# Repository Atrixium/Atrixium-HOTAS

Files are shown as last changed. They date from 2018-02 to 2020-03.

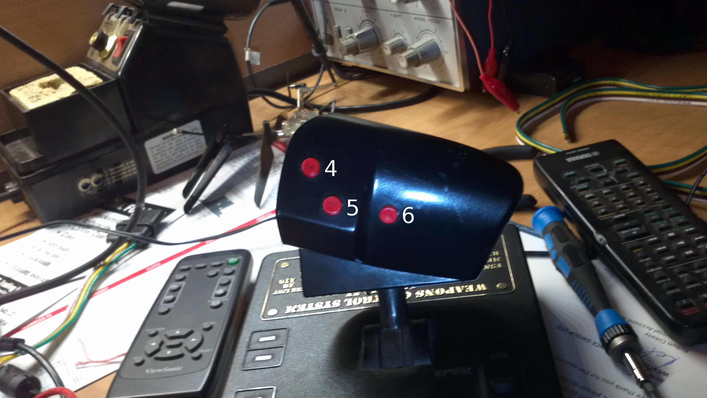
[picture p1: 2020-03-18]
Finger Tip Buttons.png

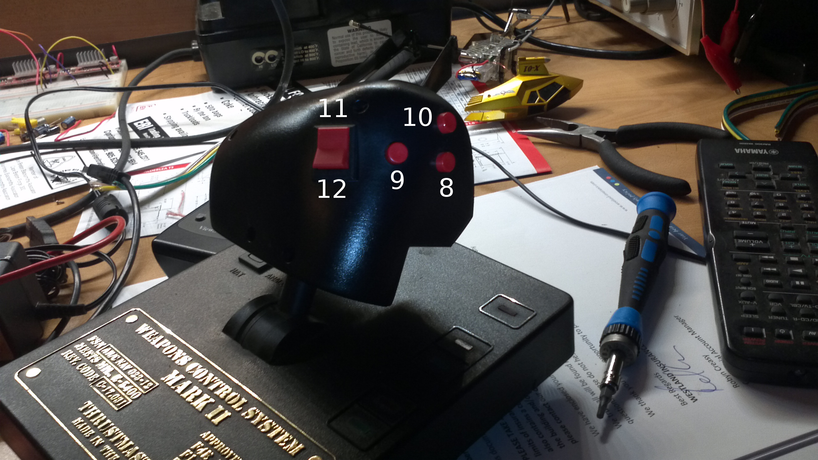
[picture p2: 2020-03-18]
Thumb Buttons.png

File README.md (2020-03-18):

# Atrixium-HOTAS

This is a simple HOTAS flight stick for Sparkfun Pro Micro boards (and clones) it uses the excellent NicoHood Gamepad API as the core https://github.com/NicoHood/HID as well as leveraging the SPI library for efficiently reading the shift registers. The code is pretty rough but is functional and it's fast enough for real gameplay, I have plans to integrate a better ADC in the future in the form of the Adafruit ADS1115 16bit, 4 channel ADC.

Schematics and board files are in CADsoft Eagle format.

Additional info on this HOTAS can be found on my Youtube channel: https://www.youtube.com/user/Atrixium

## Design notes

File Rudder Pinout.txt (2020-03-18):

Mini DIN connecter MD-60s

1 - Ground - Grn
5 - Analog Data - White
4 - VCC - Yel
6 - Digital Data

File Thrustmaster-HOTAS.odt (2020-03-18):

Thrustmaster Top Gun, WCS MK II HOTAS
& Rudder System

Objective:

Convert Thrustmaster WCS MK II into base unit for Top Gun Flightstick and custom rudder pedals for use with modern games on a Linux system. Peripherals attach to WCS MK II and it connects to PC via USB.

Specifications:

Top Gun
2 Axes, 4 Buttons, 4 Pos POV hat (Analog)

15 pin DSUB output

WCS MK II
1 Axis, 6 buttons, 2 on-off-on rocker switches, 1 on-off rocker switch
15 pin DSUB input (for Top Gun)

6 Pin mini din (MD-60S) input for rudder

USB A Output

Rudder Pedals
1 axis, 1 button

6 Pin mini din (MD-60S)

Components:

x1 Pro Micro Microcontroller running NicoHood\HID Library https://github.com/NicoHood/HID/wiki
x2 MC74HC165A 8 bit PISO shift registers for button scanning

x2 MD-60S Connectors for rudder connection

Process:

Joystick pots need to be rewired to allow for direct reading of the pots, they currently have signal and VCC connections. VCC must be moved to an outer position, signal must be moved to the wiper and a ground must be added. Throttle will be entirely rewired, switches and buttons are all common grounded.

Pinouts


Analog | Digital
A0) Flightstick X | MISO) SR Data out (SR Pin 9 or 7 for inverse)
A1) POV Hat | SCLK) SR Clock (SR Pin 2)
A2) Flightstick Y | 10) SR Shift/Load (SR Pin 1)
A9) Throttle
A3) Rudder

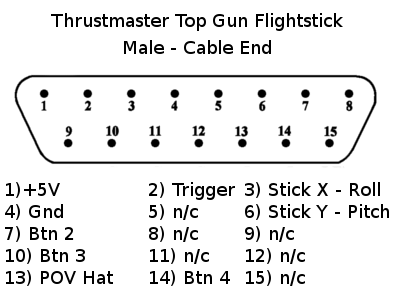
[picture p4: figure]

gnd - yellow | btn1 – red | btn2 – purple | btn3 – blue | btn4 – green | vcc - orange & brown

Function Description

A button is pressed which pulls its corresponding data line low, setting the shift register input to low, the microcontroller shifts in 2 bytes of data from the shift registers inverted output via SPI and processes it by bit-masking to determine which buttons are pressed, this should be executed as many times per second as possible.

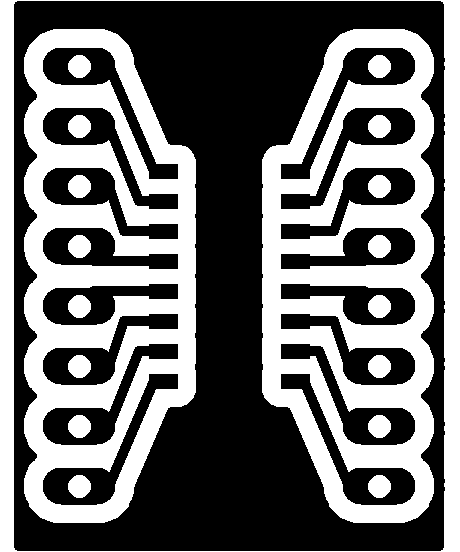
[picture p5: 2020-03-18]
SO16 Breakout v2.png

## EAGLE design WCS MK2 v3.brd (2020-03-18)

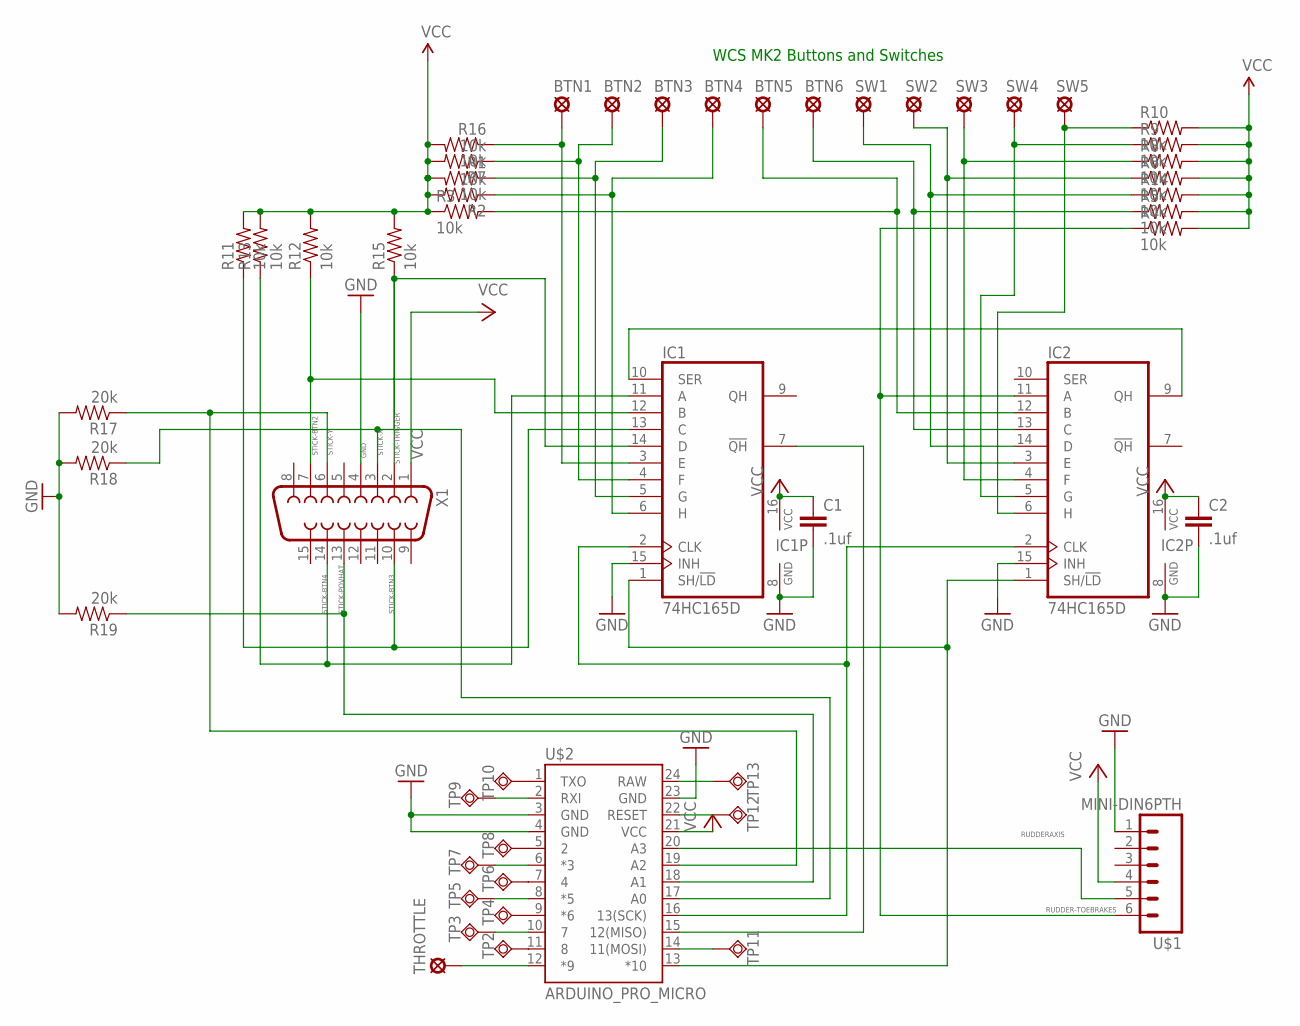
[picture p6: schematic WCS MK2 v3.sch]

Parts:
BTN1, BTN2, BTN3, BTN4, BTN5, BTN6: LSP10
C1, C2: .1uf; C025-060X050
IC1, IC2: 74HC165D; SO16
R1, R2, R3, R4, R5, R6, R7, R8, R9, R10, R11, R12, R13, R14, R15, R16: 10k; AXIAL-0.1
R17, R18, R19: 20k; AXIAL-0.1
SW1, SW2, SW3, SW4, SW5: LSP10
THROTTLE: LSP10
TP2, TP3, TP4, TP5, TP6, TP7, TP8, TP9, TP10, TP11, TP12, TP13: TPSQTP20SQ; TP20SQ
U$1: MINI-DIN6PTH; MINI-DIN6
U$2: ARDUINO_PRO_MICRO
X1: F15HP

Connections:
CLOCK: IC1.2 (CLK), IC2.2 (CLK), U$2.16 (13(SCK))
DAISYCHAIN: IC1.10 (SER), IC2.9 (QH)
GND: C1.2, C2.2, IC1.8 (GND), IC1.15 (INH), IC2.8 (GND), IC2.15 (INH), R17.P$2 (2), R18.P$2 (2), R19.P$2 (2), U$1.1, U$2.3 (GND), U$2.4 (GND), U$2.23 (GND), X1.4
MISO: IC1.7 (!QH), U$2.15 (12(MISO))
unnamed: BTN1.MP, IC1.3 (E), R16.P$1 (1)
unnamed: BTN2.MP, IC1.4 (F), R7.P$1 (1)
unnamed: BTN3.MP, IC1.5 (G), R1.P$1 (1)
unnamed: BTN4.MP, IC1.6 (H), R2.P$1 (1)
unnamed: IC2.6 (H), R10.P$1 (1), SW5.MP
unnamed: IC2.5 (G), R9.P$1 (1), SW4.MP
unnamed: IC2.4 (F), R8.P$1 (1), SW3.MP
unnamed: IC2.3 (E), R6.P$1 (1), SW2.MP
unnamed: IC2.14 (D), R14.P$1 (1), SW1.MP
unnamed: BTN6.MP, IC2.13 (C), R5.P$1 (1)
unnamed: BTN5.MP, IC2.12 (B), R3.P$2 (2)
unnamed: TP2.TP, U$2.11 (8)
unnamed: TP3.TP, U$2.10 (7)
unnamed: TP4.TP, U$2.9 (*6)
unnamed: TP5.TP, U$2.8 (*5)
unnamed: TP6.TP, U$2.7 (4)
unnamed: TP7.TP, U$2.6 (*3)
unnamed: TP8.TP, U$2.5 (2)
unnamed: TP9.TP, U$2.2 (RXI)
unnamed: TP10.TP, U$2.1 (TXO)
unnamed: TP11.TP, U$2.14 (11(MOSI))
unnamed: TP12.TP, U$2.22 (RESET)
unnamed: TP13.TP, U$2.24 (RAW)
RUDDER-TOEBRAKES: IC2.11 (A), R4.P$1 (1), U$1.6
RUDDERAXIS: U$1.5, U$2.20 (A3)
SR-LOAD: IC1.1 (SH/!LD), IC2.1 (SH/!LD), U$2.13 (*10)
STICK-BTN2: IC1.12 (B), R12.P$1 (1), X1.7
STICK-BTN3: IC1.13 (C), R11.P$1 (1), X1.10
STICK-BTN4: IC1.11 (A), R13.P$1 (1), X1.14
STICK-POVHAT: R19.P$1 (1), U$2.18 (A1), X1.13
STICK-TRIGGER: IC1.14 (D), R15.P$1 (1), X1.2
STICK-X: R18.P$1 (1), U$2.17 (A0), X1.3
STICK-Y: R17.P$1 (1), U$2.19 (A2), X1.6
THROTTLEAXIS: THROTTLE.MP, U$2.12 (*9)
VCC: C1.1, C2.1, IC1.16 (VCC), IC2.16 (VCC), R1.P$2 (2), R2.P$2 (2), R3.P$1 (1), R4.P$2 (2), R5.P$2 (2), R6.P$2 (2), R7.P$2 (2), R8.P$2 (2), R9.P$2 (2), R10.P$2 (2), R11.P$2 (2), R12.P$2 (2), R13.P$2 (2), R14.P$2 (2), R15.P$2 (2), R16.P$2 (2), U$1.4, U$2.21 (VCC), X1.1

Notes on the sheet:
WCS MK2 Buttons and Switches

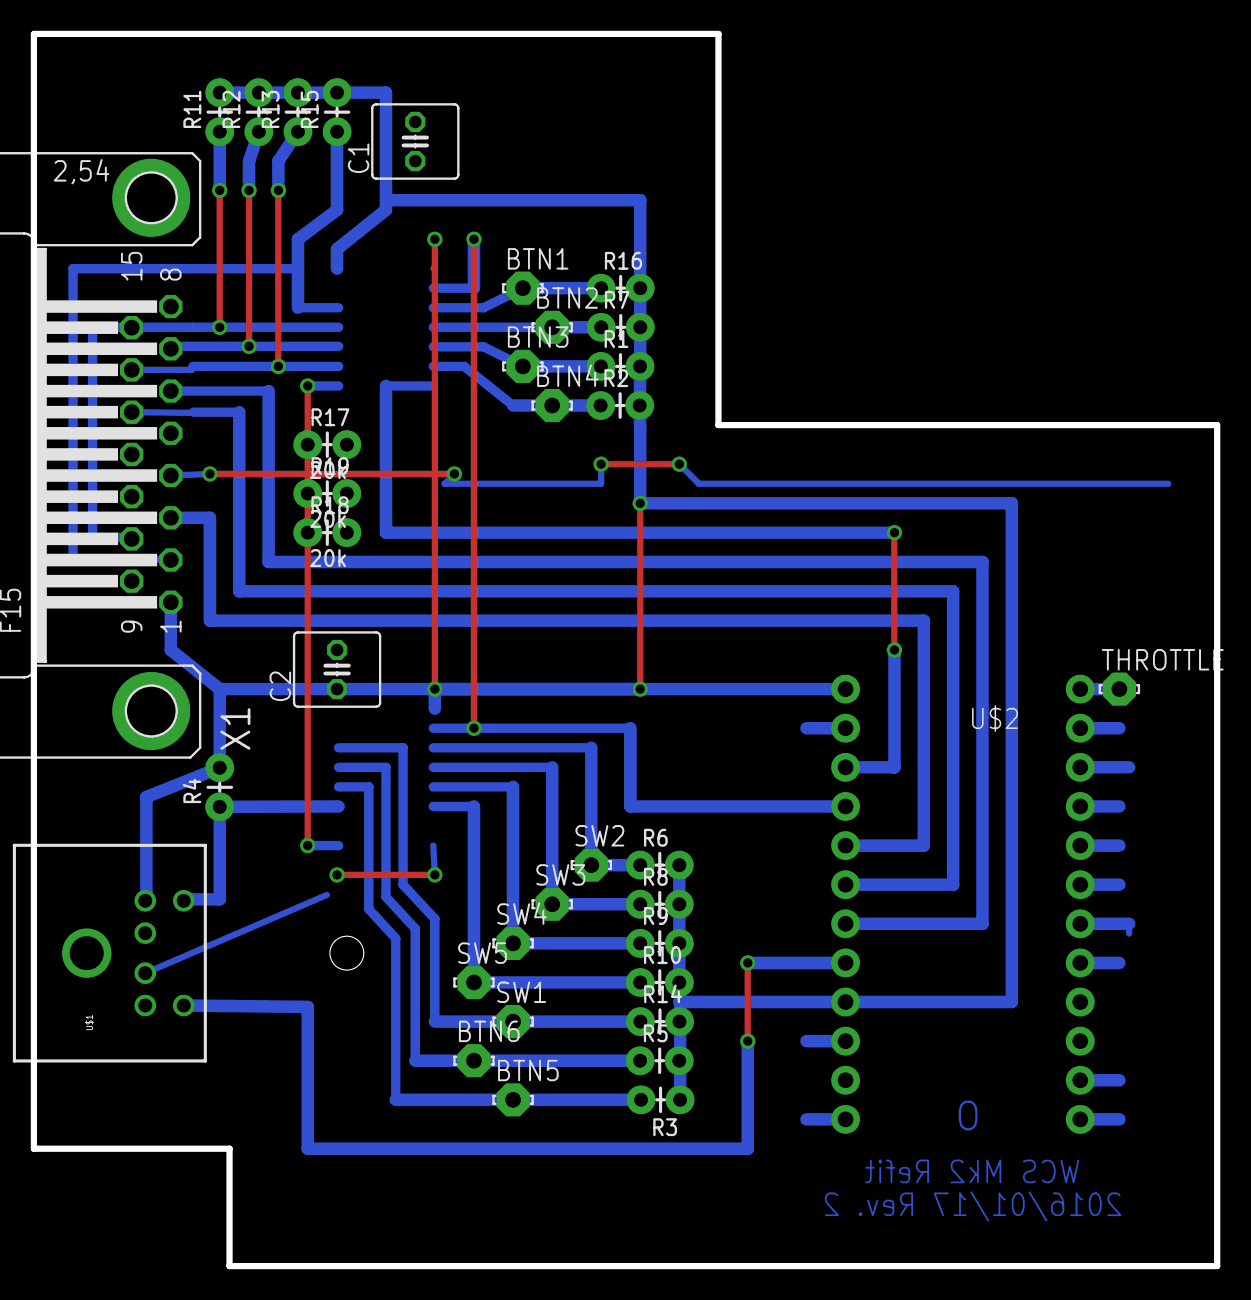
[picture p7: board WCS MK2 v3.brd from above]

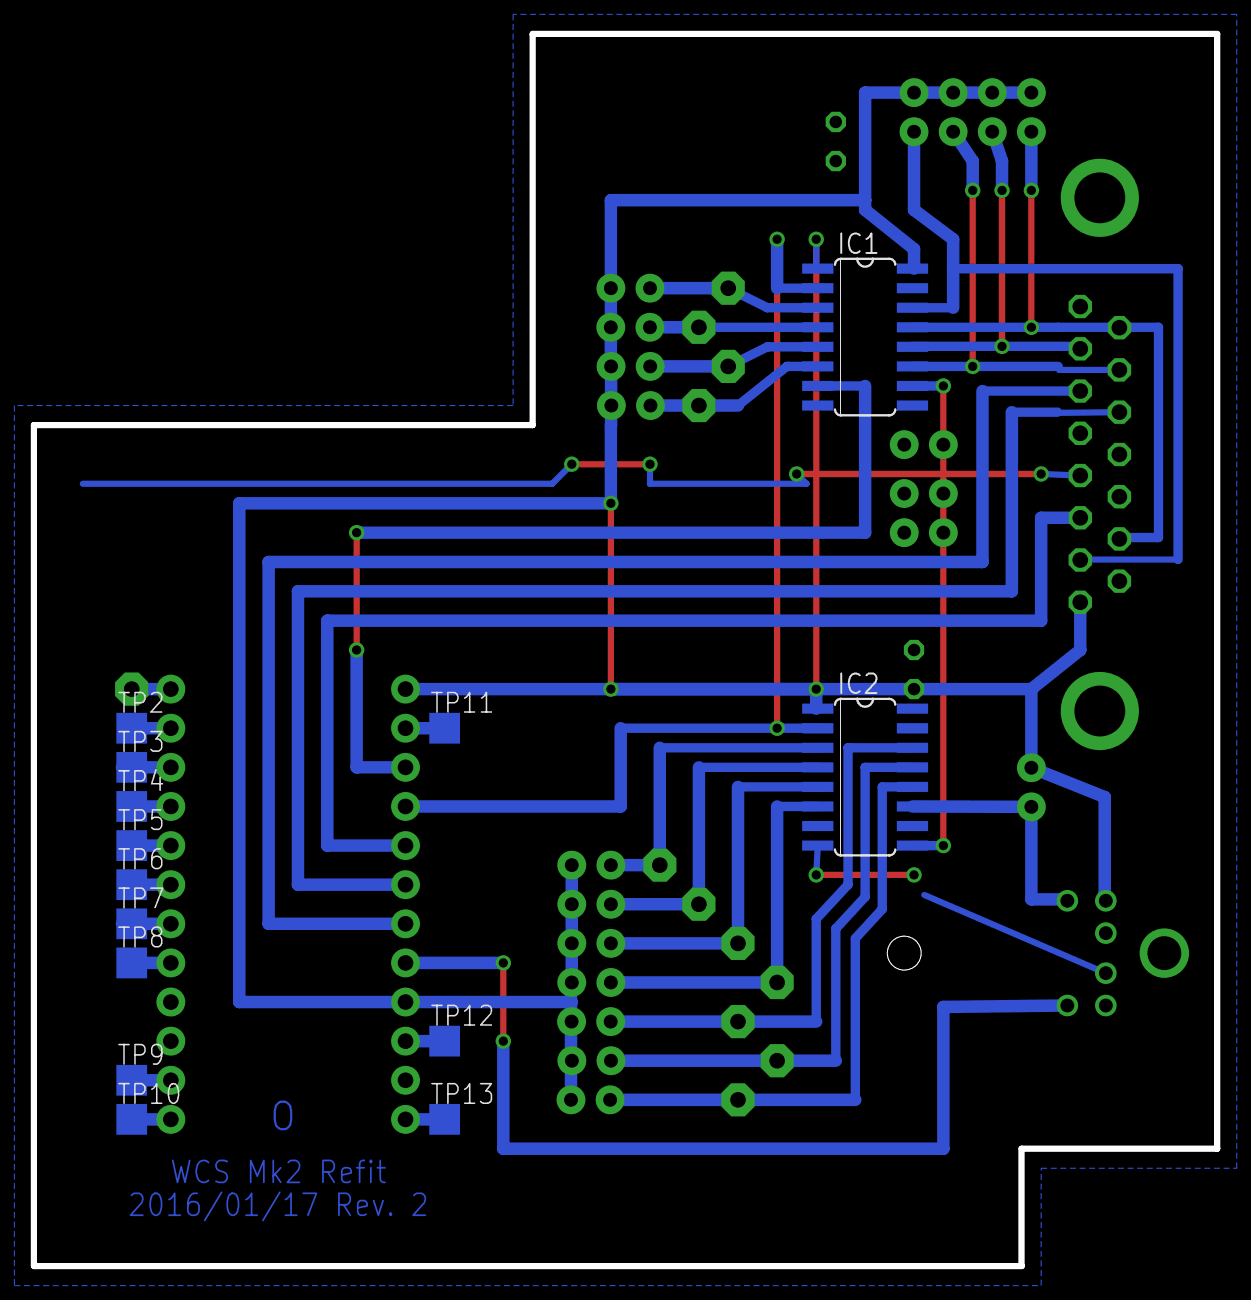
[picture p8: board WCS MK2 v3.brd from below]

Board: 2 copper layers, 76.8 x 80.0 mm, 50 parts (14 on the bottom side), 39 nets.

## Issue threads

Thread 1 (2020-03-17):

circuit schematic/pcb layout

minipc, 2020-03-17:
more of a request than issue:

i was wondering if either the circuit schematic or pcb layout for this project were available anywhere? and if not if they could be made available?

i have scrutinised frame grabs of the pcb layout and assembled pcb taken from the second and first youtubes relating to this project and am having trouble reconciling the positions of the resistors and bridging connectors visible in the finished assembly featured in the first video with positions of the solder pads of the pcb layout featured in the second video.

Atrixium, 2020-03-18:
Sorry about that, the documentation is... Not great. I never actually expected anyone else to see this project! I'm sure I have everything backed up, board layout, PCB etc, so I'll make sure to get it all on here and answer any questions you might have!

Atrixium, 2020-03-18:
I just uploaded basically all I have on the project, hopefully that helps. I remember something about having to bodge something on the board as well, so I'll take it apart later on and see if I can remember what it was.

minipc, 2020-03-18:
no need to apologise :) i guess interest in the project may largely depend on how many people happen to have vintage thrustmaster sticks and throttles they're considering upgrading to the 21st century ;)

i happen to have a basically unused thrustmaster pro flight control system stick and am wondering if it's worth trying to source a weapons control system ii throttle in order to do a conversion similar to yours, or whether to just convert the stick alone. the possibility of restricting mods to a potentially beat up second hand throttle, and leaving the stick in pristine condition seemed attractive, although i note from what you've uploaded that some modification of the stick's wiring is unavoidable.

there are a number of youtube tutorials that cover the use of shift registers and pots with arduinos. and there are clues in the arduino sketch. so i could have probably inferred that side of things, if i'd really put my mind to it. what wasn't so clear was how the game and ps2 ports connected up. which is why i reached out.

it's interesting that you mention perhaps bodging something on the pcb. while comparing the youtubes, i did wonder if i was looking at two different versions of it. indeed, the layout in the uploaded brd file is quite different from that shown in the second youtube.

thank you so much for such a speedy and thorough response. the brd file alone will be a great help. all i can think of further to ask is whether with hindsight there was anything you might have done differently, like perhaps locating the pro micro board closer to the edge of the pcb? or was there some reason to set the micro usb connector back from the side of the enclosure? actually, i think you've already done enough for the issue to be closed :)

Atrixium, 2020-03-18:
The design decisions were mostly fueled by my inexperience :) Going back and doing it again I definitely would have either mounted the micro in such a way that the USB port was easier to get to, or wired in an extension to allow better port placement. I think I also would have gone straight to the 16bit ADC, the 10 bits of precision Saree good enough and on par with most joysticks, but why not make it better :)

I think a better electrical engineer (I'm just a self-taught hobbyist) could have made the circuit work without modifying the joystick, but I couldn't figure out how to do it at the time and I also figured I'd never have another machine with a game port connection :)

Anyway, thanks for your interest in the project and I'll post any other useful tidbits as I recall them! I'd really like to finish this project and get the rudders working properly but real life keeps getting in the way!

minipc, 2020-03-19:
thanks for sharing your insights.

i'm guessing that the gameport standard involved the analogue signals being read as some kind of measurement of resistance, as the pots in the flight stick are wired up as rheostats. obviously if you ground the unconnected terminals you produce a voltage divider that can be measured directly on a arduino analogue input. you could also create a voltage divider by connecting the pot's tap terminal to a fixed value external resistor connected to ground. if you feed the tap voltage into an analogue input it won't vary linearly with stick movement. but knowing the input voltage and the fixed resistor value allows you to calculate the resistance in the pot. and that should vary linearly with stick movement. which would avoid stick modding.

regarding 10bit adc precision, busting out the digital multimeter reveals that the 10bits apply to practically the whole effective electrical angle of the 100k pots, at least on my device (your sketch suggests the same for your top gun variation.) that resolves at the end of a roughly 200mm stick to about a 0.3mm step size. which seems more than adequate. but even before resorting to high precision external adc's, you could apply the technique of oversampling and decimation to improve bit precision in software. the sketch already takes an average of five 10bit readings. taking 4 readings and applying a single right shift to the sum effectively produces 11bit precision. taking 16 readings and applying a double right shift would produce 12bit precision. and so on. but given the geometry of the stick even 12bit accuracy would seem like overkill. excessive oversampling can severly limit frequency analysis of rapidly varying signals. but that wouldn't really apply in this situation. so there's no reason not to use it, at least for 11bit precision.

just some thoughts :)

minipc, 2020-03-20:
isn't it always the way that you only spot your mistakes after you've expressed them in public? ;)

of course, using an external resistor to form a voltage divider in the way i describe reduces stick resolution. so probably not a good idea. my bad.

i've since discovered gameports measure resistance using a capacitor charging timer method. seems there's more than one way to skin this particular cat. (no cats were harmed in the creation of this post.)

Atrixium, 2020-03-23:
Yeah, my first attempt was to just add a resistor, but the lack of resolution was a problem, and then when I messed with the divider ratio I ended up with non-linearity, so in the interest of getting the project done I stuck with what I knew would work and just rewired the stick.

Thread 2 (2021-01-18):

Wow, so there's a lot going on here.

warrenernst, 2021-01-18:
Hi, it's Warren from YouTube. This seems like the best/only communication method here so...

I've just downloaded and installed Eagle and checked out the Schematic and Board files, none of which made any sense to me (WHY is he still keeping the 15-Pin gameport?) until I opened and read the ODT file and learned that the plan is to make the WCS the "brains," with the stick connecting to it via the gameport and the pedals via a 6-pin DIN connector. This would allow all three devices to connect to the computer via a single USB cable. This made good sense because a lot of older games can only accept input from one device, AND the Top Gun stick is a "dumb" analog joystick device, so why not?

My use case in 2021 is different. I already have a modern standalone pedal set which can connect via USB directly. My preferred joystick is either the vintage Thrustmaster FLCS or F-22, both of which already have shift registers built-in, so all one needs to convert one of these "smart" sticks is an Arduino micro programmed to use the shift registers and then the 5 wires from the stick connect directly, and then the two pots for the axes get wired in directly too, adding a third line to each pot. The original PCBs in the base of these sticks get discarded.

Ideally, I'm hoping to use my preferred WCS Mk II as a third standalone USB device, and even more ideally, I was hoping to NOT have to rewire button and switch on the throttle, but maybe that's just not possible? I initially thought your PCB was merely taking the existing wiring down the shaft of the throttle, connecting them somewhat neatly into the shift registers, and then THAT signal was getting processed by the Arduino micro.

Yes, this would mean my flight gear would use 3 USB connections, but modern PC games don't have any problem with mixing 3 devices into one HOTAS, AND I could more easily mix and match things over time.

Sooooo, with all that said, I guess my first question has to do with rewiring the throttle to take advantage of your shift register circuit. I assume now that it was necessary?

Or more broadly, do you see all this work you did making your WCS a "smart base" for the stick and throttle applicable to my goals? I'd love to hear your thoughts.

-Thanks

Atrixium, 2021-01-19:
For what you're looking to do, my method is probably overkill, but the same techniques would apply for a simpler circuit, although if you had enough inputs on your microcontroller you wouldn't even need the shift registers. For me the shift registers were necessary because of the number of buttons I was dealing with and my desire to use a cheap, smaller micro that I already had on hand.

As you figured out, this was all because I had some older games that only recognized one joystick at a time, so I figured I'd mash them all together into one and solve that problem, it definitely would have been much easier to just make 3 separate USB devices!

Now as for rewiring, I didn't really have to do any for the throttle itself, I just figured out what buttons referred to what wire and wired them into my board, the switches in the grip all have their commons tied together and then signal wires are broken off from each one and run down as a ribbon cable past the throttle pot,so the wiring is actually pretty straightforward. In the Throttle Wiring file I actually have the colour code that I found in mine, yours might be the same, so that could save some effort! I did rewire the throttle pot to read out a proper analog value that the Arduino could read though, just as I did with the joystick, it was just a simple matter of setting it up so the wiper went to the analog in and then I have 5V and Gnd on either side, the pot was in surprisingly good condition for it's age, but if it needs replacing, it's a standard, off-the-shelf pot.

If you don't want to go as far as ripping out the mainboard in the WCS MkII, you might be able to just tap into the wiring where it is on the board, there's some complex circuitry they put in there to handle all those buttons on the old gameport system, so I'm not sure exactly what the effect would be, at minimum you'll probably have to un-solder the switch wires. I don't recall off-hand if the stock board had a shift register to handle all the switches or not, I do remember there being a lot of glue logic chips in there though and rather than reverse engineer it, I just ripped it all out and started fresh.

If you do decide to go the shift register route, it's way easier than it looks, I just hooked the shift registers up in a daisy chain, wired them to the SPI lines on the Arduino and used the SPI library to clock in the shift register data as fast as possible, one Byte at a time and then aggregated the two bytes into one 16 bit variable with each bit representing a button; once you have that, a bit of bit-masking gets you the switch status and the whole thing only takes a couple milliseconds.

For your setup, after conversion to USB, I'd be tempted to add a USB hub into all that empty space in the WCS Mk2 so your other peripherals could plug into it and you only have one wire going to the PC!

Hopefully that answered your questions, but if not, shoot back and we'll work it out!

warrenernst, 2021-04-03:
Thanks for your detailed reply. Since we've chatted, I've dissected a newer Thrustmaster Attack Throttle and figured out its internal Shift Register scheme, documented it on Reddit for someone, who followed my instructions and successfully converted it with a Pro Micro. I've ordered up some Pro Micros myself and plan on doing the same...

And then finally this morning I took apart a WCS Mk II. Actually, I went to my stash and found one I opened up years ago (in 2000!) and then went to town tracing it out with my newfound knowledge in my head. I'm surprised how simple it is. 9 wires to the handle through the stalk with a common ground between all 7 buttons and the 1 switch going to 8 pads on the original PCB. Then 3 wires for the Pot. And then a few extra wires for the two switches on the base.

No need for a shift register circuit at all if I use a board with enough button inputs. I think the Teensy 2.0 has a few more than a Pro Micro - need to double check that and then see if it is even necessary.

Good idea about tucking in a small USB hub in the base of the throttle.

I'll be in touch with progress. Probably in a couple of months.

warrenernst, 2021-04-09:
So if you don't mind, can I run some things by you? I have some Arduino Pro Micros coming, along with some SN74HC165 Shift Register circuit boards like this one (https://www.sparkfun.com/products/retired/11512 ), but because I've never actually used them before, or the MMJoy2 software everyone seems to be using, I guess I don't know the best plan of attack.
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
warrenernst, 2021-04-10:
Oh, or now that I've stepped away from it a little bit, it seems what I've really got here is a 1x8 button matrix, huh?

Atrixium, 2021-04-10:
It sounds like you're on the right track, I used an individual resistor for
each signal pin so that I could pull each signal high and then they would
be brought to ground when a button is pressed; I actually reused the
resistor networks from the original WCS board where I could and had to add
a few discrete resistors for the extra buttons. I think if I was to do it
again, I would have gone with surface mount resistors, that was a lot of
holes to drill, in fact I probably would have used surface mount everything
to eliminate as much drilling as possible!

If you use a microcontroller that has enough inputs, you might find that
the microcontroller actually has built in pull ups and that would allow you
to forgo any external pullup resistors; in the case of the shift register
though, I found I needed a pullup for each button to get clean signals. Of
course you can choose to sense on High instead of Low signals, but you
would still need a pulldown resistor for each signal wire, I found it was
easier to stick with convention on this and I think you will too.

Those shift register breakout boards are basically what I modelled my
prototype boards after, I could have ordered some, but I'm
notoriously cheap and like to do things the hard way :D I also wanted to
make them universal so I could use them with any SO16 chip I wanted to try
out, they make breadboarding so much easier! The fact that those 74HC165s
are so cheap is what brought me to use them, you can get better ones that
use less power and switch faster, but these definitely do the job for a
good price.

Me personally, I would stick with the Pro Micro and the shift registers
because I already know that works, you could basically rip the code as it
is and modify it to suit your needs and set your board up however you like,
if you even want to use a board, there's no reason you couldn't dead bug
it, I just like making PCBs :)

My best advice would be to breadboard it all out and try it before
committing a design, you might find a method that works better, my design
spent a long time as a huge breadboard monstrosity before I design and make
the board.

Keep me posted on what you decide to do and good luck!

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

warrenernst, 2021-05-10:
Hi again. So I have a completed project to share with you.

So I'm done, and have successfully converted one of my WCS Mk II throttles to USB, using an Arduino Pro Micro board and MMJoy2 software. As it turns out, whereas most TM gear from this era uses a Shift Register, the WCS Mk II uses a 1x8 button matrix for the buttons and switch in the handle, and as a result, it's really easy to convert.

All it took was snipping off the 9 wires from the handle to the original PCB, using the White wire (which TM uses as a common ground for all the handle buttons) as the "1" in the 1x8 matrix, and then the other 8 wires are the "8" in the 1x8 matrix, meaning you need 9 free pins on your Pro Micro to wire them up. I just crimped female Dupont connectors and then stuck them right on the Pro Micro. There are enough free pins on my board to also connect the two switches on the base, meaning it's a 4x10 matrix using only 11 button positions, but the "wasted" buttons don't mean a thing. And of course, the pot wires up to an analog pin along with a VCC and Ground pin.

So far, I've converted an FLCS, and F-22 Pro, an Attack Throttle, and now this WCS Mk II, and by now I've gotten the process for any of these down to about an hour. Next are some TQS throttles, but I'm awaiting more Pro Micros. I have a few more to convert for spares.

Anyway, I wanted to thank you for posting your original videos and the project here to inspire me to finally getting to this project,. It's been fun, and I'm looking forward to using this stuff again. If you have any interest in my pinouts, photos, or MMJoy2 settings for any of this hardware, let me know and I'll be happy to share. Take care.

warrenernst, 2021-05-11:
Thanks Rob. For the time being, I have my work posted on Reddit here: https://www.reddit.com/r/HotasDIY/comments/n9k22l/thrustmaster_wcs_mk_ii_throttle_converted_to_usb/

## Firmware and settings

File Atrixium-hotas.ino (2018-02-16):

/*
  Thrustmaster HOTAS based on NicoHood Gamepad API - Rob Street 2016
  
  Copyright (c) 2014-2015 NicoHood
  See the readme for credit to other people.

  See HID Project documentation for more infos
  https://github.com/NicoHood/HID/wiki/Gamepad-API
*/

#include "HID-Project.h"
#include <SPI.h>

//### Debugging Variables ###
unsigned long StartTime = 0;
unsigned long EndTime = 0;

const bool DebugButtons = 0; // enable or disable debug messages, very slow!
const bool DebugAxes = 0; // enable or disable debug messages, very slow!


//### Define Pins ####
const int Load = 10; // Shift register load pin
const int StickX = A0;
const int StickY = A2;
const int POVHat = A1;
const int Rudder = A3;
const int Throttle = A9;
const int Analog5 = A5;


//### input variables ###

byte HighByte = 0b01010101;
byte LowByte = 0b10101010;
unsigned int Input = 0xCCCC;

int xRaw = 0; // 16BIT
int yRaw = 0; // 16BIT
int zRaw = 0; // 8BIT

int rxRaw = 0; // 16BIT
int ryRaw = 0; // 16BIT
int rzRaw = 0; // 8BIT

long xAxis = 0; // 16BIT
long yAxis = 0; // 16BIT
int zAxis = 0; // 8BIT

long rxAxis = 0; // 16BIT
long ryAxis = 0; // 16BIT
int rzAxis = 0; // 8BIT

int JOYSTICK_DEADZONE = 310;

//### Analog Averaging Variables ###
int samples = 5;

//###### Define Button Bits ########

unsigned int Button[16] = {0x1,0x2,0x4,0x8,
                   0x10,0x20,0x40,0x80,
                   0x100,0x200,0x400,0x800,
                   0x1000,0x2000,0x4000,0x8000};

//##################################

void setup() {
  pinMode(Load, OUTPUT);

  // Start SPI functions
  SPI.begin();

  // Debug console
  {
    if(DebugButtons || DebugAxes)
      Serial.begin(9600);
  }

  // Sends a clean report to the host. This is important on any Arduino type.
  Gamepad.begin();
}

void loop() {

  digitalWrite(Load, LOW); // Load shift registers
  digitalWrite(Load, HIGH); // Set shift registers to shifting mode
  HighByte = SPI.transfer(0xff); // Grab the first byte
  LowByte = SPI.transfer(0xff); // Grab the second byte
  
  if(DebugButtons)
  {
    Serial.print("HighByte: ");
    Serial.println(HighByte,BIN);
    Serial.print("LowByte: ");
    Serial.println(LowByte,BIN);
  }
  
  Input = HighByte * 256 + LowByte; // Combine high byte and low byte into one 16bit variable
  
  if(DebugButtons)
  {
    Serial.print("Input=  ");
    Serial.println(Input,BIN);
  }

    // Press buttons
    if(DebugButtons)
    {
      StartTime = micros(); // Get the start time for the button polling
    }
      
    for(int i=0; i<=15; i++)
    {
      if(Input & Button[i]) // Compare input to mask
      {
        Gamepad.press(i);
        if(DebugButtons)
        {
          Serial.print("Pressing: ");
          Serial.println(i);
        }
      }
      else
      {
        Gamepad.release(i);
        if(DebugButtons)
        {
          Serial.print("Releasing: ");
          Serial.println(i);
        }
      }
    }

    if(DebugButtons)
    {
      EndTime = micros(); // Get the end time for the button polling
      Serial.print("Polling took: ");
      Serial.println(EndTime - StartTime);
    }
    

    // Get X, Y, Z, RX, RY and RZ axes

    xRaw = GetAxis(StickX);
    yRaw = GetAxis(StickY);
    zRaw = GetAxis(POVHat); // 8bit
    
    rxRaw = GetAxis(Throttle);
    ryRaw = GetAxis(Rudder);
    //rzRaw = GetAxis(Analog5);// 8bit

    //Map X,Y,RX,RY to 16 Bit
    
    xAxis = map(xRaw, 0, 1023, -32767, 38000);
    xAxis = abs(xAxis) < JOYSTICK_DEADZONE ? 0 : xAxis;
    xAxis = constrain(xAxis, -32767,32767);
    
    yAxis = map(yRaw, 0, 1023, -32767, 40000);
    yAxis = abs(yAxis) < JOYSTICK_DEADZONE ? 0 : yAxis;
    yAxis = constrain(yAxis, -32767,32767);
    
    rxAxis = map(rxRaw, 0, 768, -32767, 32767);
    rxAxis = abs(rxAxis) < JOYSTICK_DEADZONE ? 0 : rxAxis;
    rxAxis = constrain(rxAxis, -32767,32767);
    
    ryAxis = map(ryRaw, 0, 521, -32767, 32767);
    // ryAxis = abs(ryAxis) < JOYSTICK_DEADZONE ? 0 : ryAxis;
    ryAxis = constrain(ryAxis, -32767,32767);
    
    // Map Z and RZ axes to 8 bit
    zAxis = map(zRaw, 210, 1023, -255, 254);
    //rzAxis = map(zRaw, 0, 1023, -255, 254);


    // Move Axes to a new position
    Gamepad.xAxis(xAxis);
    Gamepad.yAxis(yAxis);

    Gamepad.rxAxis(rxAxis);
    Gamepad.ryAxis(ryAxis);
    
    Gamepad.zAxis(zAxis);
    //Gamepad.rzAxis(rzAxis);

    
    if(DebugAxes)
    {
      Serial.print("X Raw: ");  
      Serial.println(xRaw);
      Serial.print("X Mapped: ");  
      Serial.println(xAxis);
      Serial.print("Y Raw: ");  
      Serial.println(yRaw);
      Serial.print("Y Mapped: ");  
      Serial.println(yAxis);
      Serial.print("Z Raw: ");  
      Serial.println(zRaw);
      Serial.print("Z Mapped: ");  
      Serial.println(zAxis);
      
      Serial.print("RX Raw: ");  
      Serial.println(rxRaw);
      Serial.print("RX Mapped: ");  
      Serial.println(rxAxis);
      Serial.print("RY Raw: ");  
      Serial.println(ryRaw);
      Serial.print("RY Mapped: ");  
      Serial.println(ryAxis);
      Serial.print("RZ Raw: ");  
      Serial.println(rzRaw);
      Serial.print("RZ Mapped: ");
      Serial.println(rzAxis);}
    // Functions above only set the values.
    
    // This writes the report to the host.
    Gamepad.write();

    // Simple debounce
    //delay(300);
}

int GetAxis(int Axis){
  int result = 0;
  for(int i=0; i<samples; i++){
    result = result + analogRead(Axis);  // Read an Axis
  }
  result = result / samples; // Get Average
  return result;
}

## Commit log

2020-03-18 Add files via upload
    Added schematic, board layout, SO16 breakout board, Top Gun pinouts and original design document.
    [S016 Breakout Board v2.brd, WCS MK2 v3.brd, WCS MK2 v3.sch]
2020-03-18 Add files via upload
    Add button, throttle and rudder wiring info

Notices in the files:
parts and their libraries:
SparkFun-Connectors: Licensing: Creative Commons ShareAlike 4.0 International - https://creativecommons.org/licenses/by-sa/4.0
